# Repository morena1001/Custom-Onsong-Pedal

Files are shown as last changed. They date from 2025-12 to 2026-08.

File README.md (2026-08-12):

# Custom Onsong Pedal
A custom keyboard based pedal for Onsong, 
a songbook application used for organizing 
songs. 

Onsong is a songbook app with the ability 
to customize chords, add capo,  and create
sets or playlists. This app also supports 
pedals to be able to change songs, chords, 
etc. handsfree. They offer their own pedals, 
or a custom keyboard based pedal with support for at most 8 different characters that converts keyboard presses into inputs. This project
implements a custom keyboard pedal for use in live performances.

This pedal was developed to solve an issue I was having. I am part of my church's worship team, and changing the song or scrolling through them forces me to take a hand away from the piano. By having foot pedals to control those actions, I can keep playing while keeping up with the current song.

This project uses the [ESP32 BLE Keyboard library](https://github.com/T-vK/ESP32-BLE-Keyboard), which handles BLE communication and transmission of keystrokes. The software uses a simple for loop that continuously checks for button presses and makes use of a software debounce to filter out acidental presses or interference. 

Hardware wise, the project uses the [HiLetgo ESP-WROOM-32S](https://www.amazon.com/dp/B0718T232Z?ref=ppx_yo2ov_dt_b_fed_asin_title&th=1), a USB-C, 5V 2A boost converter with lithium battery charging protection board, and a 3.7V, 1600mAh Li-Po battery. This setup provides the pedals with enough power to last several worship services on a single charge. 

The design for the pedals take on a modular approach. Each button or pedal has its own individual case, and when connected via magnetic pogo connectors to either the main pedal that houses all of the hardware components, or the chain of pedals already connected to the main pedal, power is provided to that pedal and it can then transmit its associated character.

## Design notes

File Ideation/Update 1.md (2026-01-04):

# Update, 1 / 4 / 26

I have decided to make a few changes that I will document here. 

### Modular pedal blocks
Firstly, the full pedal will be divided into blocks, where each block will have a pedal and correspond to a character ('a' - 'h'). The main block will also house the MCU and the battery. Each block will have at least one magentic, pogo pin based port that can easily connect to the other blocks. The main block and the last one, the one that corresponds to the letter 'h', will only have one port, signifying the start and end of the entire pedal system. The blocks will ideally have a small curve to them so that they don't stretch for too much and not fit underneath the piano. 

This past week I have been trying to create a consistent pogo pin connector setup, and have created many iterations. I am waiting to receive some new, stronger magnets to be able to handle the pressure and force created by the loaded springs on the pogo pins.

### Rechargeable battery
I have yet to start working on the rechargeable battery system for the main pedal block, but I don't think it should be too difficult. After doing some research. I think my easiest option would be to use an Ni-CD battery. The way to charge them safely is to simply use a resistor to limit the current. That option though might make it slow to charge. On the other hand, I could buy an li-ion battery and buy an actual module that will allow me to safely control the battery charge. 

I could also just use 4 AA or 3 AA batteries to power the whole thing, and honestly, I don't think that would be a bad idea. I could save money trying different solutions to create a rechargeable battery.

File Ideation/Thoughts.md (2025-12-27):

Onsong has some limits to its custom pedal:
- A max number of 8 inputs are available for the pedal  
- There is a scroll function
- There is an extra forward pedal ? 
- There are mac command key based shortcuts

Total number of pedal inputs:
8 (+1?) + scroll

Possible configurations:
- Page
  - adjust 
  - up
  - down
  - switch

- Scroll
  - adjust 
  - up
  - down
  - top
  - bottom

- Section
  - adjust 
  - previous
  - next
  - switch

- Set
- Song
- Viewport
- Zoom
- Key

Confirmed input commands: 
- Page up
- Page down
- Set switch
- Song previous
- Song next
- Key up
- Key down

Input commands to investigate:
- Scroll up
- Scroll down
- Set previous
- Set next
- Key adjust
- Key change

The pedal has to be a keyboard pedal, with a character mapped to an input

I will repurpose the ESP32 to communicate with the iPad via BT.
- I could use the BLEkeyboard library to easily emulate a library, but has a caveat where I need to use a third party app to connect with the iPad.
- I could also use the ad2p library that sets up an actual BT connection, visible through the settings app, but may be harder to implement a keyboard because this library is primarily focused on sharing music via BT.
  - I could try to figure out how the BT is implemented and do it myself, but could and will take more time.

I think both libraries are worth a shot.

I want the pedal to have a rechargeable battery with a power indicator via BT and an LED. It can recharge via USB-C.

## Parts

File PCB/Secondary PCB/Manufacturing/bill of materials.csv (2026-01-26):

Reference | Value | Datasheet | Footprint | Qty | DNP
J1 | Conn_01x03_Socket | ~ | Connector_PinHeader_2.54mm:PinHeader_1x03_P2.54mm_Vertical | 1
J2,J4 | Conn_01x09_Socket | ~ | Connector_PinHeader_2.54mm:PinHeader_1x09_P2.54mm_Vertical | 2
J3 | Conn_01x07_Socket | ~ | Connector_PinHeader_2.54mm:PinHeader_1x07_P2.54mm_Vertical | 1

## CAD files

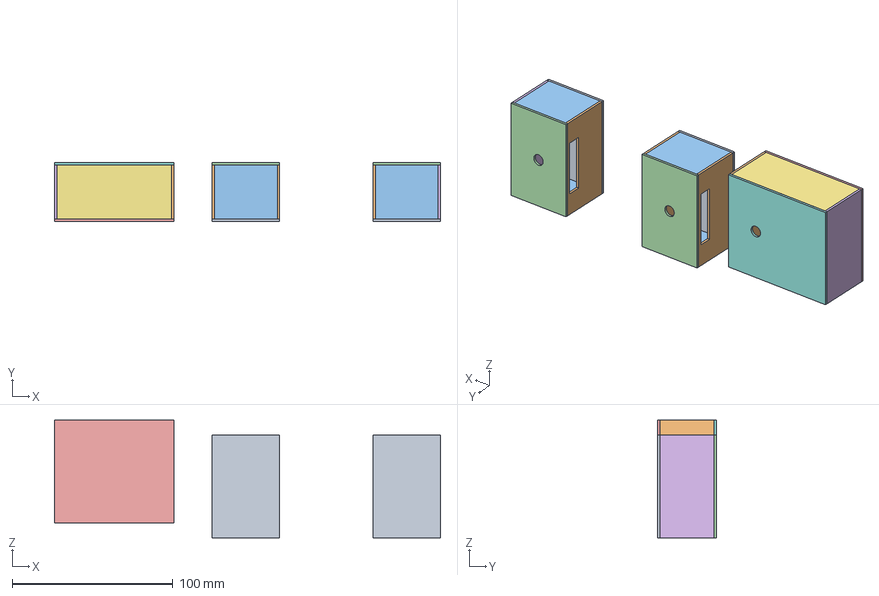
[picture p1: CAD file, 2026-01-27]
Enclosure/Onsong Pedals v2.step
240.0 x 36.6 x 73.3 mm
Secondary pedal case
Parts
Base pedal case
Secondary pedal case end

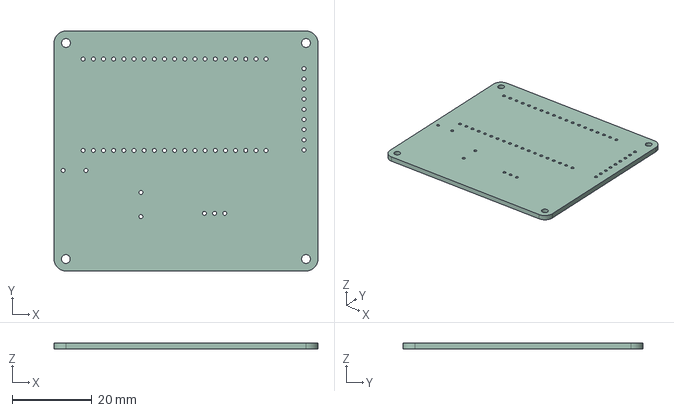
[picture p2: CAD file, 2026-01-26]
PCB/Base PCB/PCB.step
66.0 x 60.0 x 1.60 mm

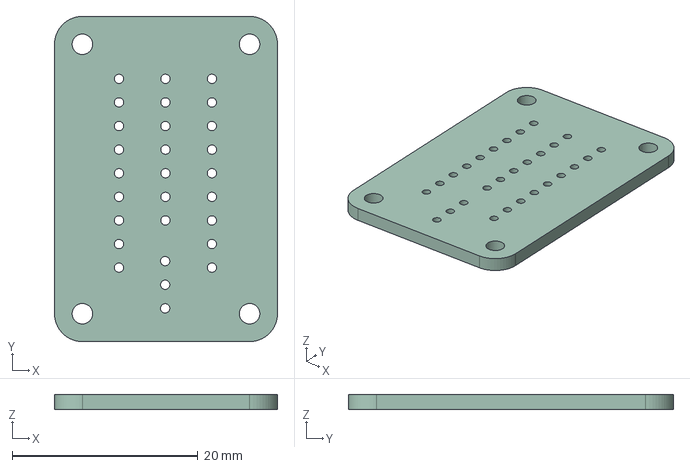
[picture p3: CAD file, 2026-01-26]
PCB/Secondary PCB/Secondary PCB.step
24.0 x 35.0 x 1.60 mm

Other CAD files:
Enclosure/Onsong Pedals v1.step
Enclosure/Onsong Pedals v1.f3d
Enclosure/Onsong Pedals v2.f3d
PCB/Base PCB/PCB.3mf

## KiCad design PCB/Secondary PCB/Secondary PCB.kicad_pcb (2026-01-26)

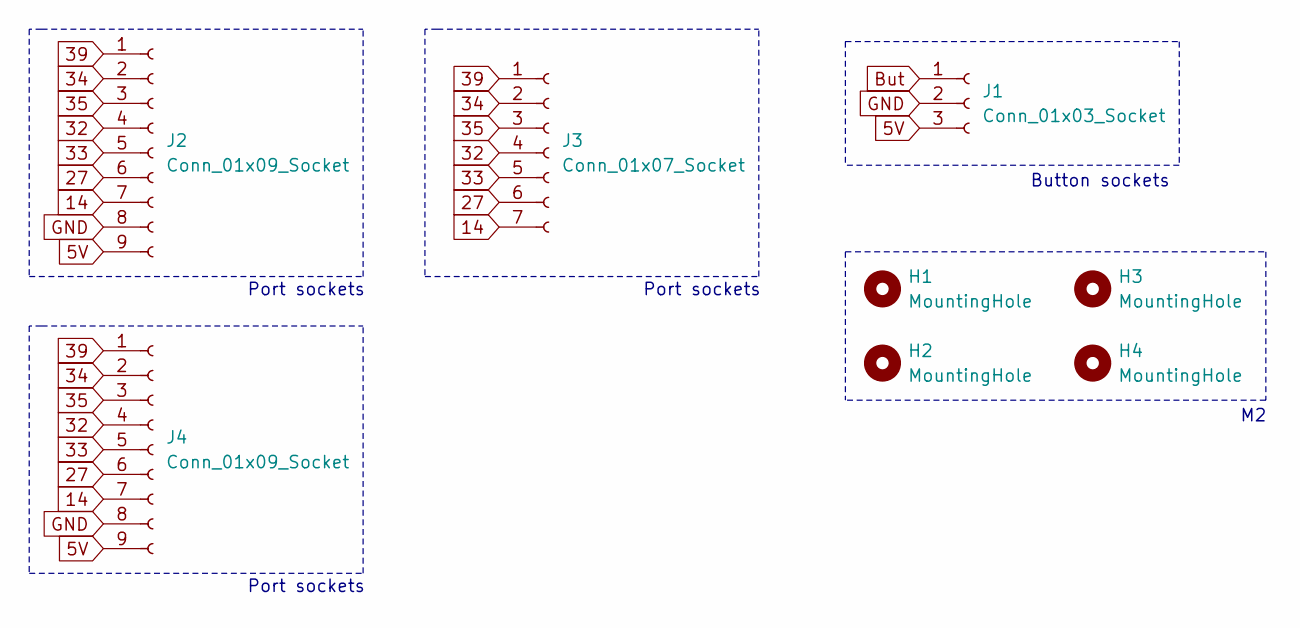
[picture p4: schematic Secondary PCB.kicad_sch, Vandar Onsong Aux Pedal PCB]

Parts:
H1, H2, H3, H4: MountingHole; MountingHole_2.2mm_M2
J1: Conn_01x03_Socket; PinHeader_1x03_P2.54mm_Vertical
J2, J4: Conn_01x09_Socket; PinHeader_1x09_P2.54mm_Vertical
J3: Conn_01x07_Socket; PinHeader_1x07_P2.54mm_Vertical

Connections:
5V: J1.3, J2.9, J4.9
14: J2.7, J3.7, J4.7
27: J2.6, J3.6, J4.6
32: J2.4, J3.4, J4.4
33: J2.5, J3.5, J4.5
34: J2.2, J3.2, J4.2
35: J2.3, J3.3, J4.3
39: J2.1, J3.1, J4.1
But: J1.1
GND: J1.2, J2.8, J4.8

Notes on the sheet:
Button sockets
Port sockets

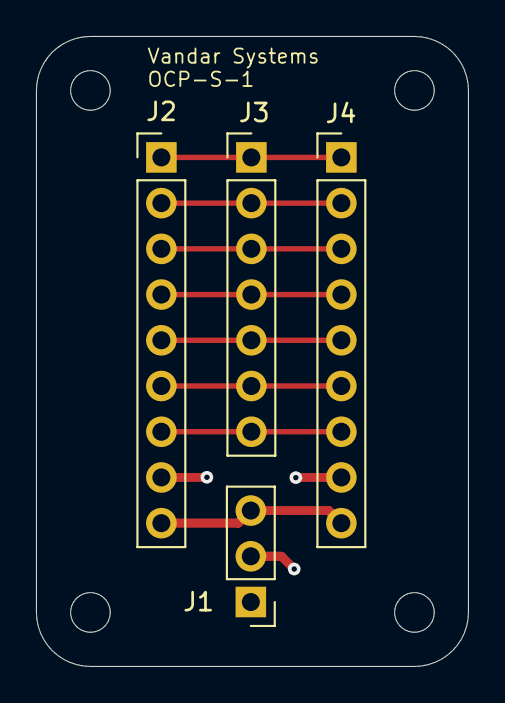
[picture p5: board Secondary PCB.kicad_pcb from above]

Board: 2 copper layers, 24.0 x 35.0 mm, 8 parts (0 on the bottom side), 9 nets.

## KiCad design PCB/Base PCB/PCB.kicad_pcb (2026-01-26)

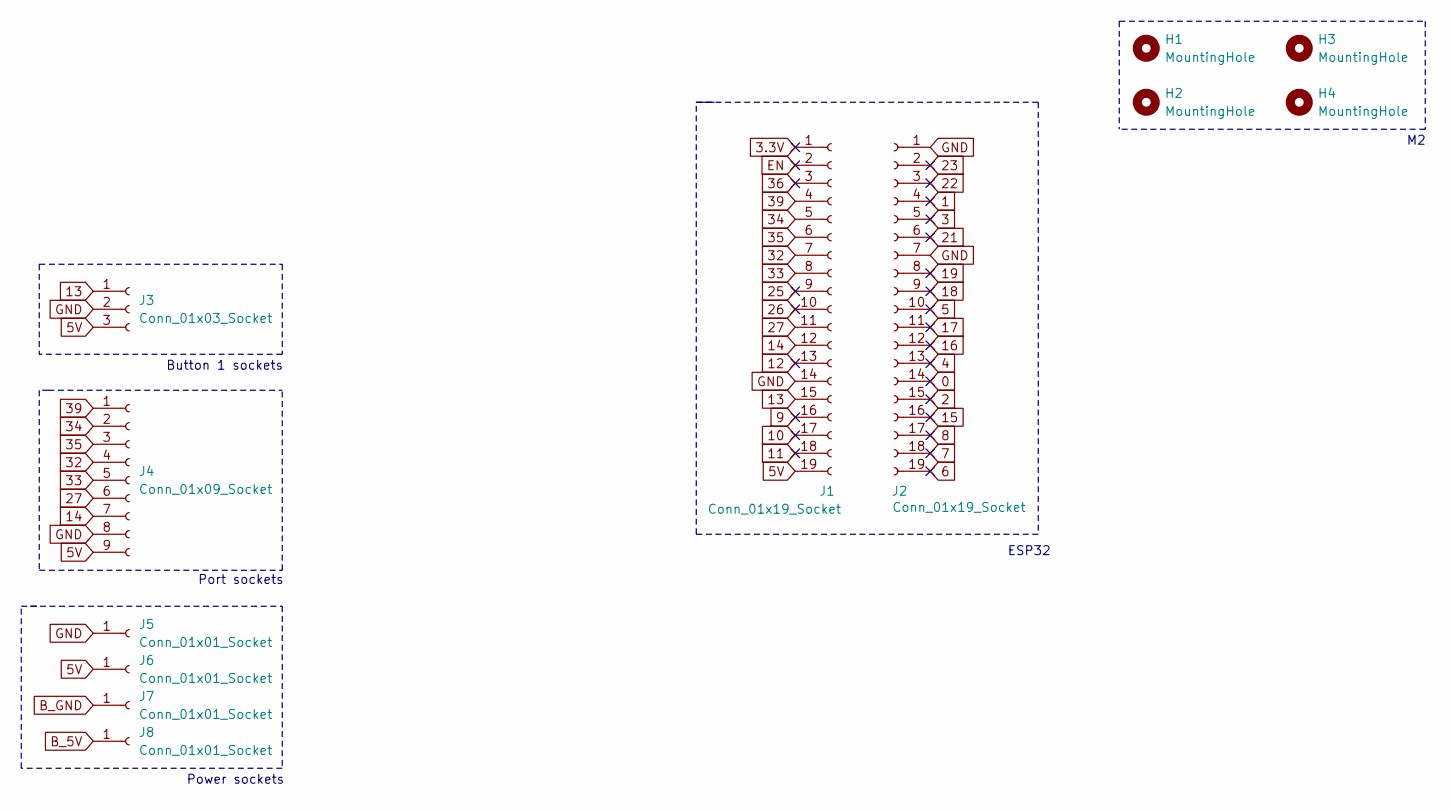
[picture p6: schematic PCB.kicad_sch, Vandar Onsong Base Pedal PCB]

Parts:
H1, H2, H3, H4: MountingHole; MountingHole_2.2mm_M2
J1, J2: Conn_01x19_Socket; PinHeader_1x19_P2.54mm_Vertical
J3: Conn_01x03_Socket; PinHeader_1x03_P2.54mm_Vertical
J4: Conn_01x09_Socket; PinHeader_1x09_P2.54mm_Vertical
J5, J6, J7, J8: Conn_01x01_Socket; PinHeader_1x01_P2.54mm_Vertical

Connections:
0: J2.14
1: J2.4
2: J2.15
3: J2.5
3.3V: J1.1
4: J2.13
5: J2.10
5V: J1.19, J3.3, J4.9, J6.1
6: J2.19
7: J2.18
8: J2.17
9: J1.16
10: J1.17
11: J1.18
12: J1.13
13: J1.15, J3.1
14: J1.12, J4.7
15: J2.16
16: J2.12
17: J2.11
18: J2.9
19: J2.8
21: J2.6
22: J2.3
23: J2.2
25: J1.9
26: J1.10
27: J1.11, J4.6
32: J1.7, J4.4
33: J1.8, J4.5
34: J1.5, J4.2
35: J1.6, J4.3
36: J1.3
39: J1.4, J4.1
B_5V: J8.1
B_GND: J7.1
EN: J1.2
GND: J1.14, J2.1, J2.7, J3.2, J4.8, J5.1

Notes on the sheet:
Power sockets
ESP32
Port sockets
Button 1 sockets

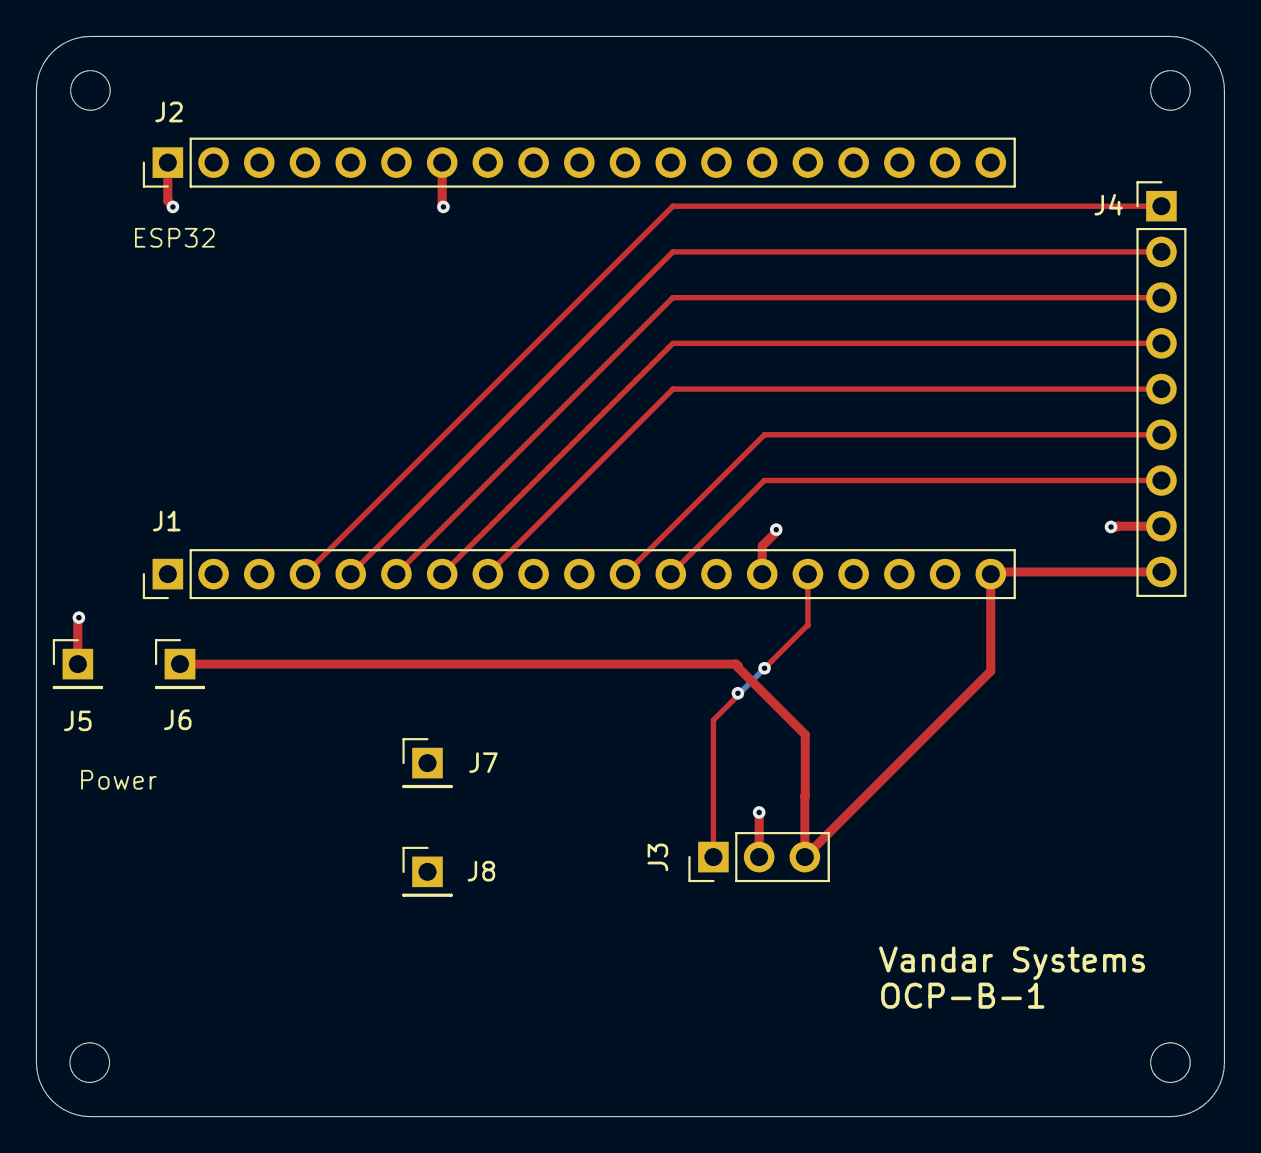
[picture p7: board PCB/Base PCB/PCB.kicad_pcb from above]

Board: 2 copper layers, 66.0 x 60.0 mm, 12 parts (0 on the bottom side), 10 nets.

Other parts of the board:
H2#2: MountingHole; MountingHole_2.2mm_M2

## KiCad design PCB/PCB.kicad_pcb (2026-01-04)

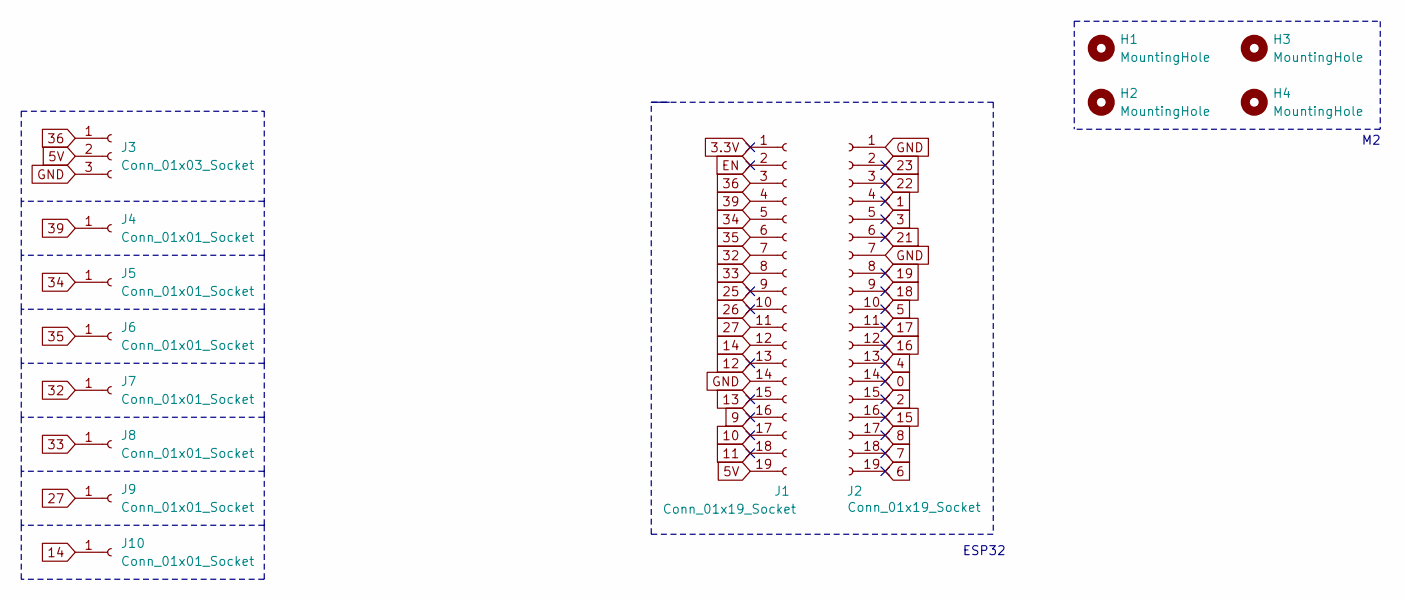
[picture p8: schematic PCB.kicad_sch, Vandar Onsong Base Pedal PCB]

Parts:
H1, H2, H3, H4: MountingHole; MountingHole_2.2mm_M2
J1, J2: Conn_01x19_Socket; PinHeader_1x19_P2.54mm_Vertical
J3: Conn_01x03_Socket; PinHeader_1x03_P2.54mm_Vertical
J4, J5, J6, J7, J8, J9, J10: Conn_01x01_Socket; PinHeader_1x01_P2.54mm_Vertical

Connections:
0: J2.14
1: J2.4
2: J2.15
3: J2.5
3.3V: J1.1
4: J2.13
5: J2.10
5V: J1.19, J3.2
6: J2.19
7: J2.18
8: J2.17
9: J1.16
10: J1.17
11: J1.18
12: J1.13
13: J1.15
14: J1.12, J10.1
15: J2.16
16: J2.12
17: J2.11
18: J2.9
19: J2.8
21: J2.6
22: J2.3
23: J2.2
25: J1.9
26: J1.10
27: J1.11, J9.1
32: J1.7, J7.1
33: J1.8, J8.1
34: J1.5, J5.1
35: J1.6, J6.1
36: J1.3, J3.1
39: J1.4, J4.1
EN: J1.2
GND: J1.14, J2.1, J2.7, J3.3

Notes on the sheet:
ESP32

Board: 2 copper layers, 14 parts (0 on the bottom side), 10 nets, no tracks yet.

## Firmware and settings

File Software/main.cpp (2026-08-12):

#include <Arduino.h>
#include <BleKeyboard.h>

BleKeyboard keyboard ("Onsong pedal");

// PINS ON ESP32
#define PEDAL_1_PIN   13
#define PEDAL_2_PIN   39 
#define PEDAL_3_PIN   34 
#define PEDAL_4_PIN   35 
#define PEDAL_5_PIN   32 
#define PEDAL_6_PIN   33 
#define PEDAL_7_PIN   27 
#define PEDAL_8_PIN   14 

// SOFTWARE DEBOUNCE DELAY
#define DB_DELAY      50

// TIMER FOR EACH BUTTON
unsigned long pedal_1_last_db_time = 0;
unsigned long pedal_2_last_db_time = 0;
unsigned long pedal_3_last_db_time = 0;
unsigned long pedal_4_last_db_time = 0;
unsigned long pedal_5_last_db_time = 0;
unsigned long pedal_6_last_db_time = 0;
unsigned long pedal_7_last_db_time = 0;
unsigned long pedal_8_last_db_time = 0;

// PRESSED STATE OF EACH BUTTON; TRUE = PRESSED, FALSE = UNPRESSED
int pedal_1_state;
int pedal_2_state;
int pedal_3_state;
int pedal_4_state;
int pedal_5_state;
int pedal_6_state;
int pedal_7_state;
int pedal_8_state;

int pedal_1_last_state = LOW;
int pedal_2_last_state = LOW;
int pedal_3_last_state = LOW;
int pedal_4_last_state = LOW;
int pedal_5_last_state = LOW;
int pedal_6_last_state = LOW;
int pedal_7_last_state = LOW;
int pedal_8_last_state = LOW;

void setup () {
  pinMode (PEDAL_1_PIN, INPUT);
  pinMode (PEDAL_2_PIN, INPUT);
  pinMode (PEDAL_3_PIN, INPUT);
  pinMode (PEDAL_4_PIN, INPUT);
  pinMode (PEDAL_5_PIN, INPUT);
  pinMode (PEDAL_6_PIN, INPUT);
  pinMode (PEDAL_7_PIN, INPUT);
  pinMode (PEDAL_8_PIN, INPUT);

  keyboard.begin ();
}

void loop () {
  // READ STATE OF EACH BUTTON
  int pedal_1_reading = digitalRead (PEDAL_1_PIN);
  int pedal_2_reading = digitalRead (PEDAL_2_PIN);
  int pedal_3_reading = digitalRead (PEDAL_3_PIN);
  int pedal_4_reading = digitalRead (PEDAL_4_PIN);
  int pedal_5_reading = digitalRead (PEDAL_5_PIN);
  int pedal_6_reading = digitalRead (PEDAL_6_PIN);
  int pedal_7_reading = digitalRead (PEDAL_7_PIN);
  int pedal_8_reading = digitalRead (PEDAL_8_PIN);

  // START DEBOUNCE TIMER IF THE BUTTON IS A NEW STATE
  if (pedal_1_reading != pedal_1_last_state)  pedal_1_last_db_time = millis ();
  if (pedal_2_reading != pedal_2_last_state)  pedal_2_last_db_time = millis ();
  if (pedal_3_reading != pedal_3_last_state)  pedal_3_last_db_time = millis ();
  if (pedal_4_reading != pedal_4_last_state)  pedal_4_last_db_time = millis ();
  if (pedal_5_reading != pedal_5_last_state)  pedal_5_last_db_time = millis ();
  if (pedal_6_reading != pedal_6_last_state)  pedal_6_last_db_time = millis ();
  if (pedal_7_reading != pedal_7_last_state)  pedal_7_last_db_time = millis ();
  if (pedal_8_reading != pedal_8_last_state)  pedal_8_last_db_time = millis ();

  // IF THE STATE OF A BUTTON HAS PERSISTED FOR LONGER THAN THE DELAY 
  // AND THE CURRENT STATE OF THE BUTTON IS PRESSED
  // TRANSMIT THE APPROPRIATE LETTER
  if ((millis () - pedal_1_last_db_time) > DB_DELAY) {
    if (pedal_1_reading != pedal_1_state) {
      pedal_1_state = pedal_1_reading;

      if (pedal_1_state == HIGH) {
        keyboard.print ("a");
      }
    }
  }

  if ((millis () - pedal_2_last_db_time) > DB_DELAY) {
    if (pedal_2_reading != pedal_2_state) {
      pedal_2_state = pedal_2_reading;

      if (pedal_2_state == HIGH) {
        keyboard.print ("b");
      }
    }
  }

  if ((millis () - pedal_3_last_db_time) > DB_DELAY) {
    if (pedal_3_reading != pedal_3_state) {
      pedal_3_state = pedal_3_reading;

      if (pedal_3_state == HIGH) {
        keyboard.print ("c");
      }
    }
  }

  if ((millis () - pedal_4_last_db_time) > DB_DELAY) {
    if (pedal_4_reading != pedal_4_state) {
      pedal_4_state = pedal_4_reading;

      if (pedal_4_state == HIGH) {
        keyboard.print ("d");
      }
    }
  }

  if ((millis () - pedal_5_last_db_time) > DB_DELAY) {
    if (pedal_5_reading != pedal_5_state) {
      pedal_5_state = pedal_5_reading;

      if (pedal_5_state == HIGH) {
        keyboard.print ("e");
      }
    }
  }

  if ((millis () - pedal_6_last_db_time) > DB_DELAY) {
    if (pedal_6_reading != pedal_6_state) {
      pedal_6_state = pedal_6_reading;

      if (pedal_6_state == HIGH) {
        keyboard.print ("f");
      }
    }
  }

  if ((millis () - pedal_7_last_db_time) > DB_DELAY) {
    if (pedal_7_reading != pedal_7_state) {
      pedal_7_state = pedal_7_reading;

      if (pedal_7_state == HIGH) {
        keyboard.print ("g");
      }
    }
  }

  if ((millis () - pedal_8_last_db_time) > DB_DELAY) {
    if (pedal_8_reading != pedal_8_state) {
      pedal_8_state = pedal_8_reading;

      if (pedal_8_state == HIGH) {
        keyboard.print ("h");
      }
    }
  }

  // UPDATE LAST STATE WITH NEW READING
  pedal_1_last_state = pedal_1_reading;
  pedal_2_last_state = pedal_2_reading;
  pedal_3_last_state = pedal_3_reading;
  pedal_4_last_state = pedal_4_reading;
  pedal_5_last_state = pedal_5_reading;
  pedal_6_last_state = pedal_6_reading;
  pedal_7_last_state = pedal_7_reading;
  pedal_8_last_state = pedal_8_reading;
}

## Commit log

2025-12-26 Added folders to store the project files at different stages of the project. I think I can already start working on the simulation
2025-12-27 Skipped simulation because I had already developed demo before. It works, but now need to test that all of the buttons work, and mess with the input I want to use to see what I'd like to use for my f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
    [main.cpp]
2025-12-27 Fixed some errors and made sure that the code works. I think I can even connect to the foot pedal via the iPad's settings page, which I think removes the need for the 3rd party BLE app. Next I want t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
    [main.cpp]
2026-01-04 Added new files for the PCB, had to stop because I decided to change they layout of the pedals. Need to finish the pogo pin ports, and research more about what kind of battery will better suit my nee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
    [PCB.kicad_pcb, PCB.kicad_sch]
2026-01-26 Finished the rough draft for the enclosure. I used the 3d models from KiCad to get the PCB dimensions.
    [Onsong Pedals v1.f3d, Onsong Pedals v1.step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]
2026-01-27 Made updates to case files
    [Onsong Pedals v2.f3d, Onsong Pedals v2.step]
